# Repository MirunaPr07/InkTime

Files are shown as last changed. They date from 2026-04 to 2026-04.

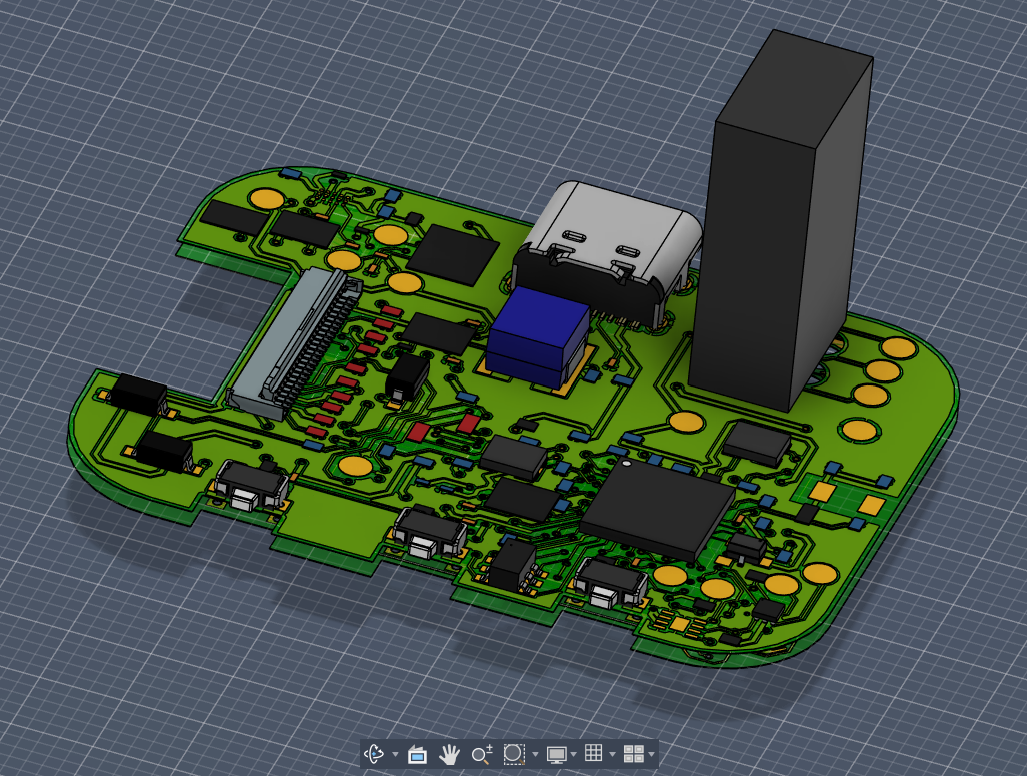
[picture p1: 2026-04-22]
Images/3d.png

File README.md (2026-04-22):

# InkWatch_TSC_Project

## Descriere

Proiectul meu este un smartwatch simplificat, cu focus pe consum redus și integrarea mai multor funcționalități pe un PCB mic. Am folosit un nRF52840 ca MCU principal și am conectat la el senzori, display e-paper și haptic.

Funcționalități:
- display e-paper
- BLE pentru comunicare
- accelerometru pentru mișcare
- feedback haptic
- încărcare USB-C

---

## Schema Bloc

```mermaid
graph TD

    USB["USB-C (J4)"] --> CHARGER["BQ25180 Charger"]
    CHARGER --> REG["RT6160 3.3V"]
    REG --> MCU["nRF52840 MCU + BLE"]

    BAT["LiPo Battery"] --> CHARGER
    BAT --> FUEL["MAX17048 Fuel Gauge"]
    FUEL --> MCU

    MCU -->|SPI| EPD["EPD Display (J1)"]
    MCU -->|I2C| IMU["BMA421 IMU"]
    MCU -->|I2C| HAPTIC["DRV2605 Haptic"]

    MCU --> BTN1["SW_UP"]
    MCU --> BTN2["SW_DN"]
    MCU --> BTN3["SW_ENT"]

    MCU --> ANT["2.4GHz Antenna"]

    MCU --> DEBUG["TC2030 SWD"]
```

## Bill of Materials

| Ref | Component | Package | Funcție | LCSC | Datasheet |
|-----|---|---|---|---|---|
| U1 | nRF52840-QIAA | QFN73 | MCU + BLE | [C190794](https://jlcpcb.com/partdetail/C190794) | https://infocenter.nordicsemi.com |
| IC1 | BQ25180YBGR | DSBGA-8 | Charger LiPo | [C3682423](https://jlcpcb.com/partdetail/C3682423) | https://www.ti.com |
| IC9 | RT6160AWSC | WLCSP-15 | Regulator 3.3V | [C7065276](https://jlcpcb.com/partdetail/C7065276) | https://www.richtek.com |
| U3 | MAX17048G+T10 | DFN | Fuel gauge | [C2682616](https://jlcpcb.com/partdetail/C2682616) | https://www.analog.com |
| IC3 | BMA421 | LGA | IMU | [C5242966](https://jlcpcb.com/partdetail/C5242966) | https://www.bosch-sensortec.com |
| IC2 | DRV2605L | VSSOP | Haptic driver | [C527464](https://jlcpcb.com/partdetail/C527464) | https://www.ti.com |
| D3 | USBLC6 | SOT-23-6 | ESD USB | [C2687116](https://jlcpcb.com/partdetail/C2687116) | https://www.st.com |
| J4 | USB-C | SMD | Conector alimentare | [C165948](https://jlcpcb.com/partdetail/C165948) | - |
| J1 | FPC 24 pini | SMD | Conector display | [C393234](https://jlcpcb.com/partdetail/C393234) | - |
| J2 | TC2030 | PTH | Debug SWD | - | - |
| ANT1 | 2450AT18B100E | SMD | Antenă BLE | - | https://www.johansontechnology.com |

---

## Funcționalitate Hardware

### Power

USB-C (5V) -> BQ25180 -> RT6160 -> 3.3V -> sistem

- BQ25180 face charging + power path
- RT6160 generează 3.3V stabil
- MAX17048 citește nivelul bateriei

---

### MCU - nRF52840

Este componenta principală:
- BLE integrat
- controlează toate perifericele

---

### Display E-Paper

Conectat prin SPI:
- SCK - P0.02
- MOSI - P0.03
- CS - P0.05
- DC - P0.15
- RST - P0.16
- BUSY - P0.17

---

### IMU - BMA421

- I2C (SDA P0.06 / SCL P0.07)
- interrupt pe P0.08 și P1.08

---

### Haptic – DRV2605

- I2C
- enable pe P0.12

---

### USB

- USB-C pentru alimentare
- protecție ESD (USBLC6)

---

## Pini nRF52840

| Pin | Semnal | Funcție |
|-----|---|---|
| P0.02 | SCK | SPI |
| P0.03 | MOSI | SPI |
| P0.05 | CS | Display |
| P0.06 | SDA | I2C |
| P0.07 | SCL | I2C |
| P0.08 | INT1 | IMU |
| P0.12 | HAPTIC_EN | Haptic |
| P0.13 | SW_UP | Buton |
| P0.14 | SW_DN | Buton |
| P0.15 | DC | Display |
| P0.16 | RST | Display |
| P0.17 | BUSY | Display |
| P1.00 | SW_ENT | Buton |
| P1.01 | EPD_PWR | Power gate |
| P1.08 | INT2 | IMU |
| P0.24 | SWDCLK | Debug |
| P0.25 | SWDIO | Debug |

---

## PCB Design

- 2 layere (Top + Bottom)
- GND polygon pour pe ambele
- trasee:
  - power: 0.3mm
  - semnal: 0.15mm

### Decizii:
- antena la margine cu keepout
- decuplare lângă IC-uri
- rutare manuală pentru trasee critice

---

## Observații

- rutare destul de densă în zona MCU
- unele trasee mai subțiri în zona BGA
- câteva GND trase manual

---

## Concluzie

Proiectul este complet funcțional din punct de vedere hardware și include toate modulele necesare pentru un smartwatch simplu.

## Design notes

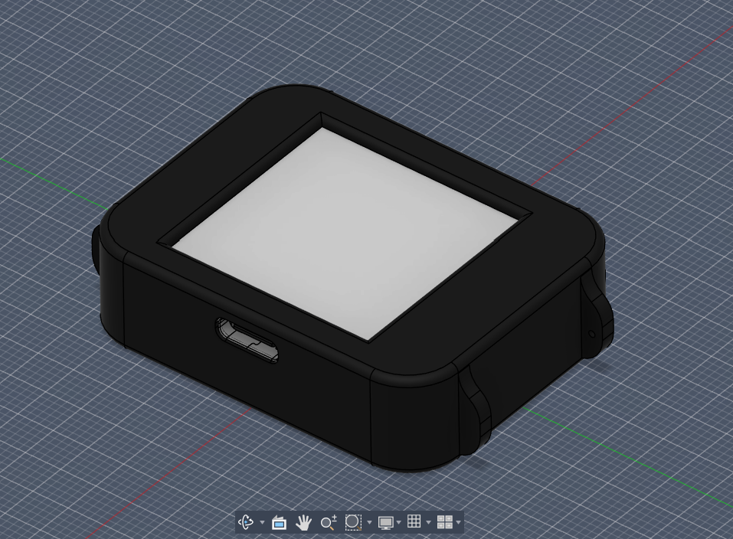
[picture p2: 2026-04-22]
Images/carcasa.png

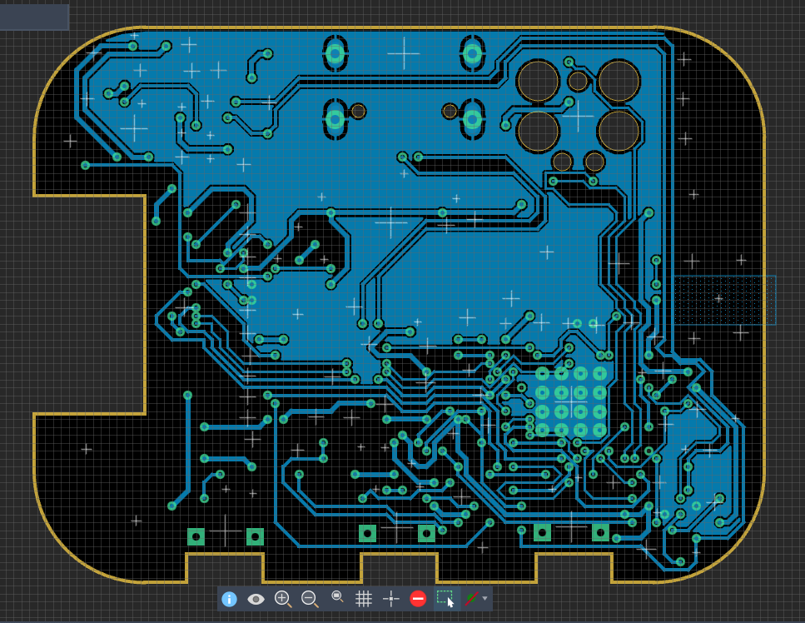
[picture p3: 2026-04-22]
Images/2d_bottom.png

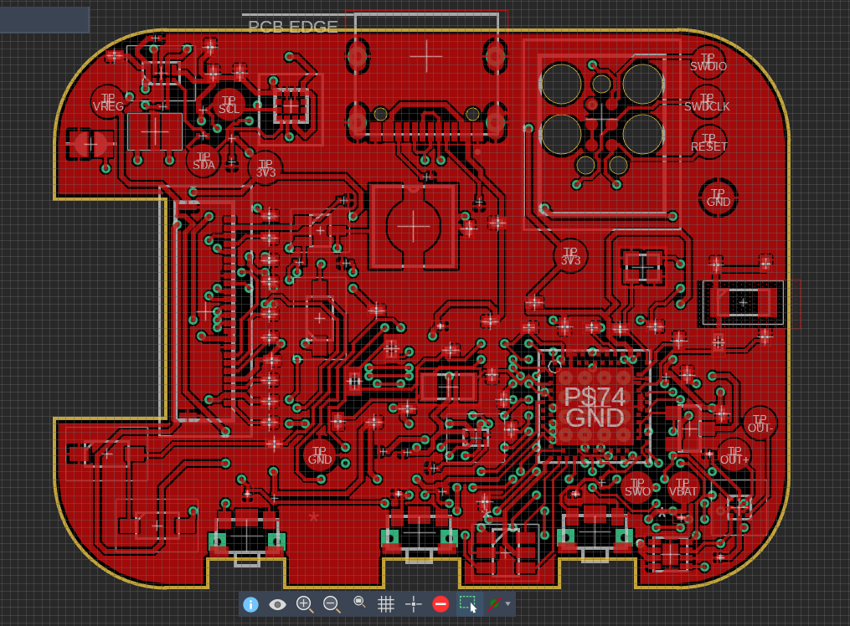
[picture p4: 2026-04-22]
Images/2d_top.png

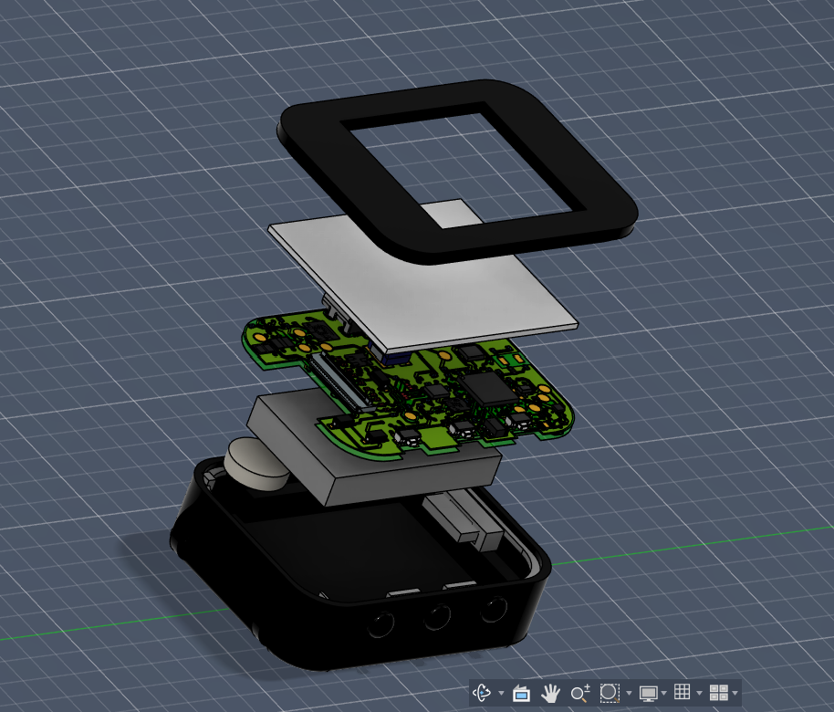
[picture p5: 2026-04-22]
Images/exploded_view.png

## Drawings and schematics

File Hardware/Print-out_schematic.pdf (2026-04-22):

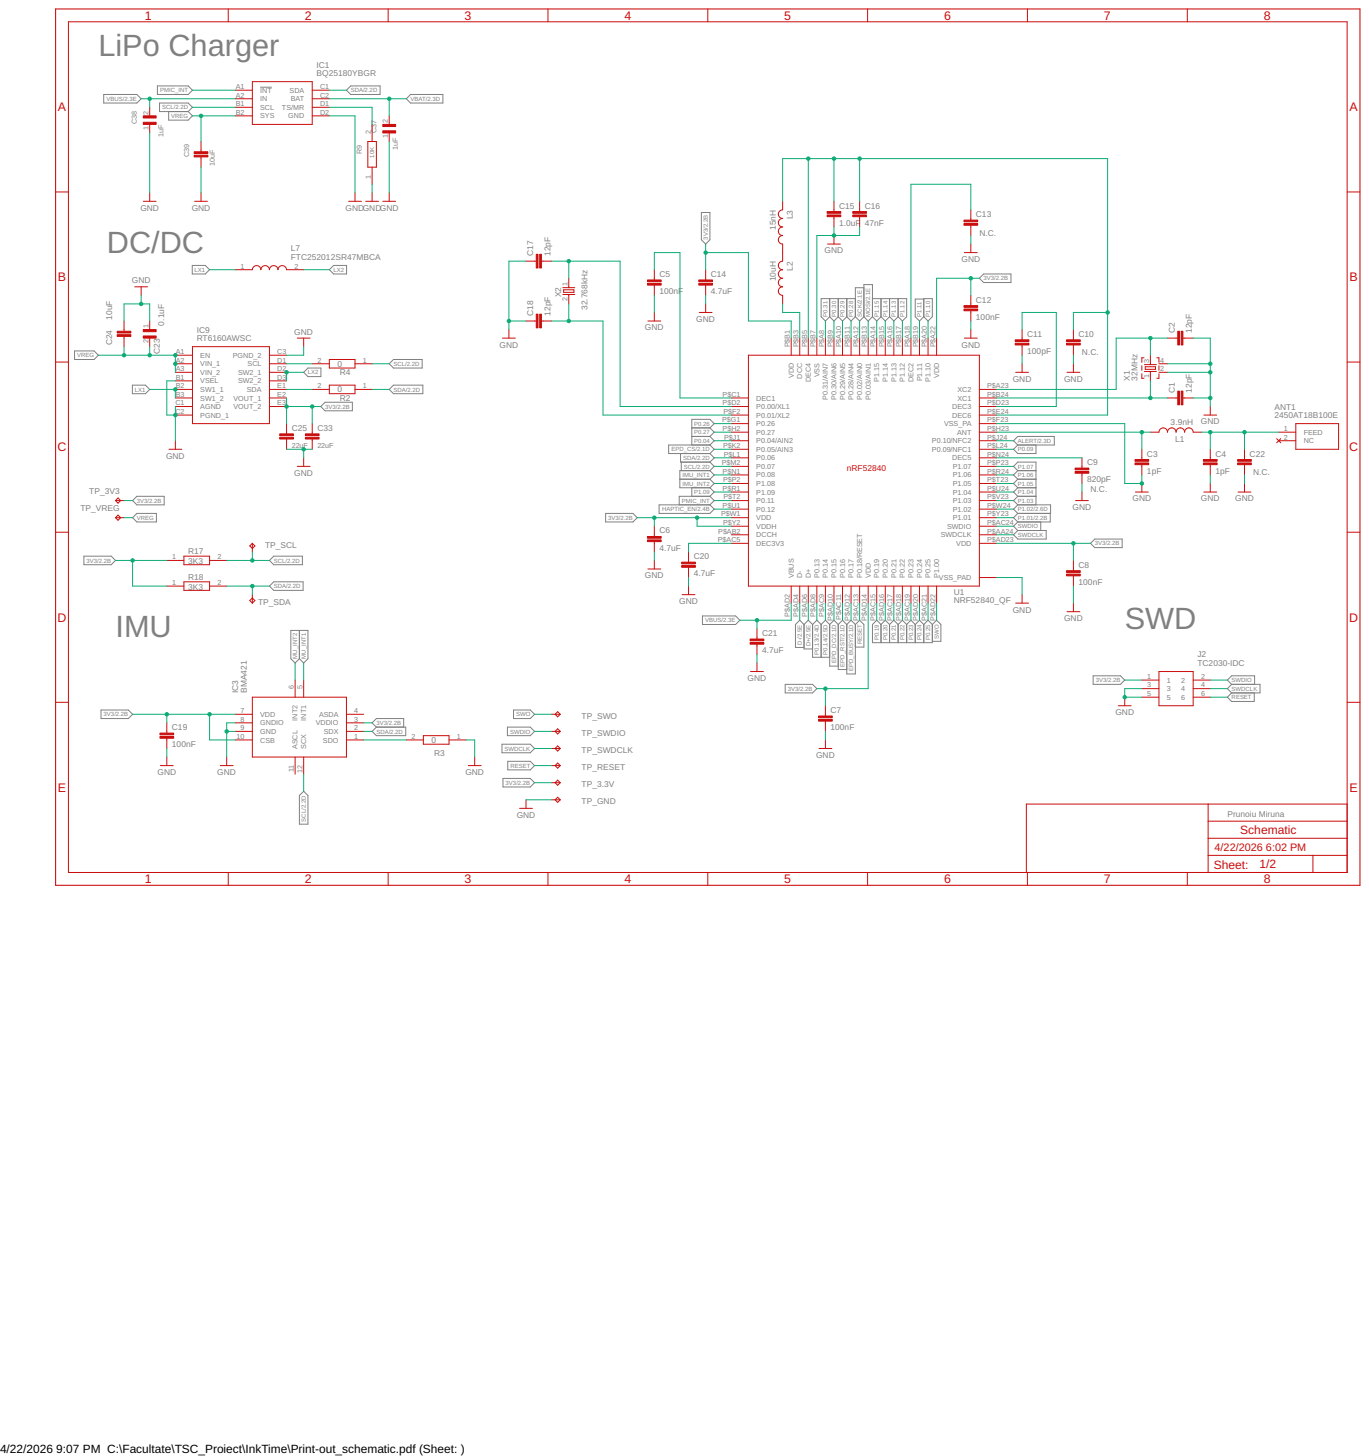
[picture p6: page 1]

4/22/2026 9:07 PM C:\Facultate\TSC_Proiect\InkTime\Print-out_schematic.pdf (Sheet: )

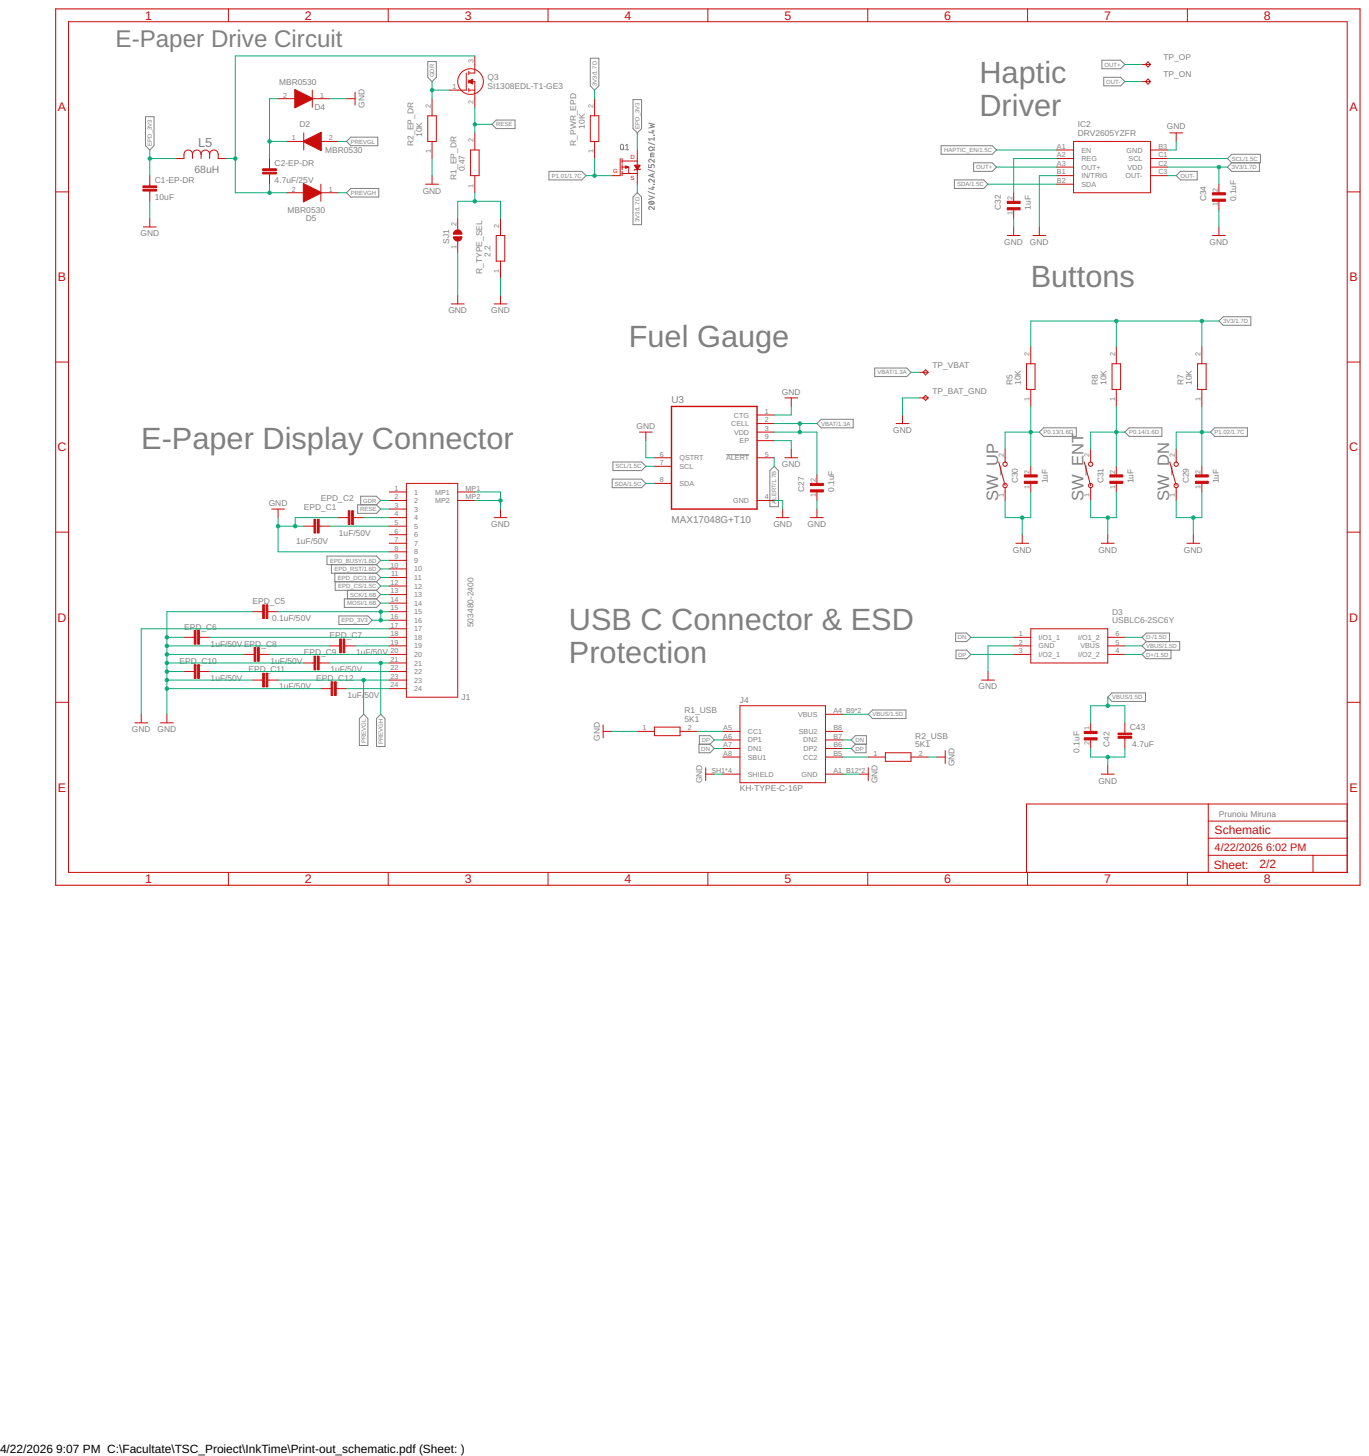
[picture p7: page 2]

EPD_C10 | 1uF/50V | 21

1uF/50V | EPD_C12 | 23

4/22/2026 9:07 PM C:\Facultate\TSC_Proiect\InkTime\Print-out_schematic.pdf (Sheet: )

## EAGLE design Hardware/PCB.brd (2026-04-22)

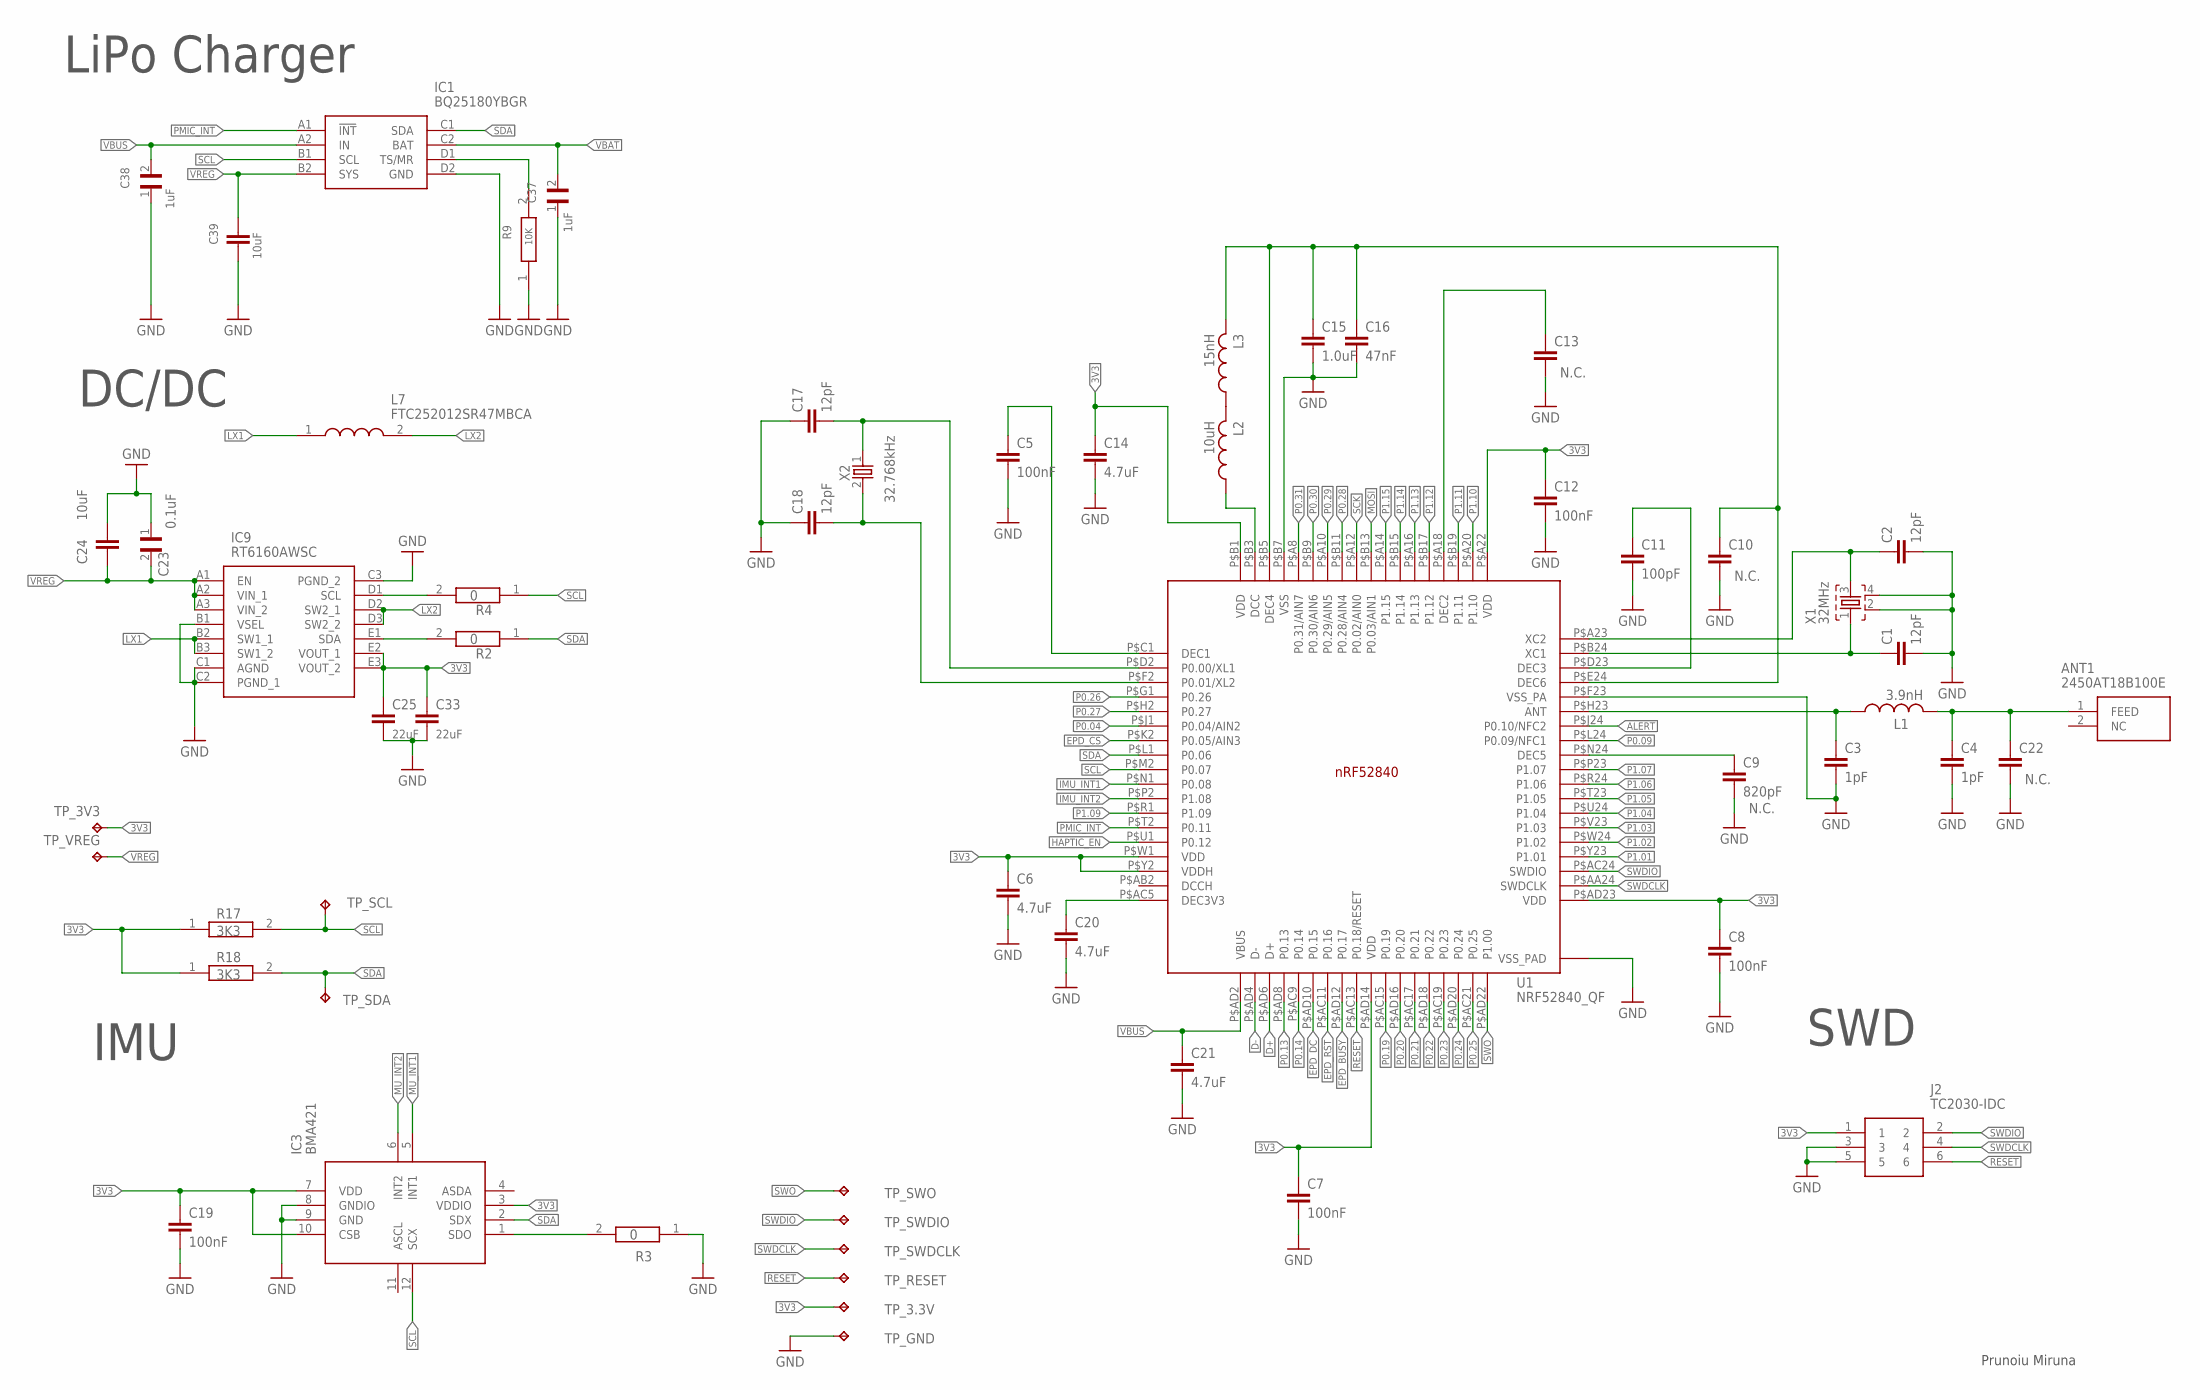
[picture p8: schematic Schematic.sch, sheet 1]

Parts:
ANT1: 2450AT18B100E; 2450AT18B100E_ANTC3216X140N
C1, C2, C17, C18: 12pF; NORDIC_NRF_3_RESC0201_L
C3, C4: 1pF; NORDIC_NRF_3_RESC0201_L
C5, C7, C8, C12, C19: 100nF; NORDIC_NRF_3_RESC0201_L
C6, C14, C20, C21: 4.7uF; NORDIC_NRF_3_RESC0201_L
C9: 820pF; NORDIC_NRF_3_RESC0201_L
C10, C13, C22: NORDIC_NRF_3_CAPACITOR_0201_L; NORDIC_NRF_3_RESC0201_L
C11: 100pF; NORDIC_NRF_3_RESC0201_L
C15: 1.0uF; NORDIC_NRF_3_RESC0201_L
C16: 47nF; NORDIC_NRF_3_RESC0201_L
C23: 0.1uF; GRM011R60J152KE01L_1_0201
C24, C39: 10uF; NORDIC_NRF_3_RESC0201_L
C25, C33: 22uF; NORDIC_NRF_3_RESC0201_L
C37, C38: 1uF; GRM011R60J152KE01L_1_0201
IC1: BQ25180YBGR; BQ25180YBGR_BGA8C40P2X4_100X155X50
IC3: BMA421; BMA423_BMA423
IC9: RT6160AWSC; RT6160AWSC_BGA15C40P3X5_140X230X60
J2: TC2030-IDC; TC2030-IDC_TC2030IDC
L1: 3.9nH; NORDIC_NRF_2_RESC0402_L
L2: 10uH; NORDIC_NRF_2_RESC0402_L
L3: 15nH; NORDIC_NRF_2_RESC0402_L
L7: FTC252012SR47MBCA; MLP2016SR47MT0S1_INDC2016X100N
R2, R3, R4: 0; CPF0201D7K68C1_0201
R9: 10K; CPF0201D7K68C1_0201
R17, R18: 3K3; CPF0201D7K68C1_0201
TP_3.3V, TP_3V3: HECTOR_WATCH_1_TPTP20R; HECTOR_WATCH_1_TP20R
TP_GND: HECTOR_WATCH_1_TPTP20R; HECTOR_WATCH_1_TP20R
TP_RESET: HECTOR_WATCH_1_TPTP20R; HECTOR_WATCH_1_TP20R
TP_SCL: HECTOR_WATCH_1_TPTP20R; HECTOR_WATCH_1_TP20R
TP_SDA: HECTOR_WATCH_1_TPTP20R; HECTOR_WATCH_1_TP20R
TP_SWDCLK: HECTOR_WATCH_1_TPTP20R; HECTOR_WATCH_1_TP20R
TP_SWDIO: HECTOR_WATCH_1_TPTP20R; HECTOR_WATCH_1_TP20R
TP_SWO: HECTOR_WATCH_1_TPTP20R; HECTOR_WATCH_1_TP20R
TP_VREG: HECTOR_WATCH_1_TPTP20R; HECTOR_WATCH_1_TP20R
U1: NRF52840_QF; NORDIC_NRF_4_AQFN50P700X700X85_HS-74N
X1: 32MHz; NORDIC_NRF_BT-XTAL_2016_N
X2: 32.768kHz; NORDIC_NRF_1_XTAL_3215_N

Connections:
3V3: C6.1, C7.1, C8.1, C12.1, C14.1, C19.1, C25.1, C33.1, IC3.3 (VDDIO), IC3.7 (VDD), IC3.10 (CSB), IC9.E2 (VOUT_1), IC9.E3 (VOUT_2), J2.1, R17.1, R18.1, TP_3.3V.TP, TP_3V3.TP, U1.P$A22 (VDD), U1.P$AD14 (VDD), U1.P$AD23 (VDD), U1.P$B1 (VDD), U1.P$W1 (VDD), U1.P$Y2 (VDDH); also elsewhere on the board
ALERT: U1.P$J24 (P0.10/NFC2); also elsewhere on the board
D+: U1.P$AD6 (D+); also elsewhere on the board
D-: U1.P$AD4 (D-); also elsewhere on the board
DEC1: C5.1, U1.P$C1 (DEC1)
DEC3: C11.1, U1.P$D23 (DEC3)
DEC4_6: C10.1, C15.1, C16.1, L3.2, U1.P$B5 (DEC4), U1.P$E24 (DEC6)
EPD_BUSY: U1.P$AD12 (P0.17); also elsewhere on the board
EPD_CS: U1.P$K2 (P0.05/AIN3); also elsewhere on the board
EPD_DC: U1.P$AD10 (P0.15); also elsewhere on the board
EPD_RST: U1.P$AC11 (P0.16); also elsewhere on the board
GND: C1.2, C2.2, C3.2, C4.2, C5.2, C6.2, C7.2, C8.2, C9.2, C10.2, C11.2, C12.2, C13.2, C14.2, C15.2, C16.2, C17.1, C18.1, C19.2, C20.2, C21.2, C22.2, C23.1, C24.1, C25.2, C33.2, C37.1, C38.1, C39.2, IC1.D2 (GND), IC3.8 (GNDIO), IC3.9 (GND), IC9.B1 (VSEL), IC9.C1 (AGND), IC9.C2 (PGND_1), IC9.C3 (PGND_2), J2.3, J2.5, R3.1, R9.1, TP_GND.TP, U1.P$74 (VSS_PAD), U1.P$75 (VSS_PAD), U1.P$76 (VSS_PAD), U1.P$77 (VSS_PAD), U1.P$78 (VSS_PAD), U1.P$79 (VSS_PAD), U1.P$80 (VSS_PAD), U1.P$81 (VSS_PAD), U1.P$82 (VSS_PAD), U1.P$83 (VSS_PAD), U1.P$84 (VSS_PAD), U1.P$85 (VSS_PAD), U1.P$86 (VSS_PAD), U1.P$87 (VSS_PAD), U1.P$88 (VSS_PAD), U1.P$89 (VSS_PAD), U1.P$90 (VSS_PAD), U1.P$B7 (VSS), U1.P$F23 (VSS_PA), X1.2, X1.4; also elsewhere on the board
HAPTIC_EN: U1.P$U1 (P0.12); also elsewhere on the board
IMU_INT1: U1.P$N1 (P0.08)
IMU_INT2: U1.P$P2 (P1.08)
LX1: IC9.B2 (SW1_1), IC9.B3 (SW1_2), L7.1
LX2: IC9.D2 (SW2_1), IC9.D3 (SW2_2), L7.2
MOSI: U1.P$B13 (P0.03/AIN1); also elsewhere on the board
MU_INT1: IC3.5 (INT1)
MU_INT2: IC3.6 (INT2)
unnamed: IC3.1 (SDO), R3.2
unnamed: IC9.E1 (SDA), R2.2
unnamed: IC9.D1 (SCL), R4.2
unnamed: C9.1, U1.P$N24 (DEC5)
unnamed: IC1.D1 (TS/MR), R9.2
unnamed: C13.1, U1.P$A18 (DEC2)
unnamed: C3.1, L1.1, U1.P$H23 (ANT)
unnamed: C1.1, U1.P$B24 (XC1), X1.1
unnamed: C2.1, U1.P$A23 (XC2), X1.3
unnamed: L2.2, L3.1
unnamed: L2.1, U1.P$B3 (DCC)
unnamed: C20.1, U1.P$AC5 (DEC3V3)
P0.00/XL1: C17.2, U1.P$D2 (P0.00/XL1), X2.1
P0.01/XL2: C18.2, U1.P$F2 (P0.01/XL2), X2.2
P0.04: U1.P$J1 (P0.04/AIN2)
P0.09: U1.P$L24 (P0.09/NFC1)
P0.13: U1.P$AD8 (P0.13); also elsewhere on the board
P0.14: U1.P$AC9 (P0.14); also elsewhere on the board
P0.19: U1.P$AC15 (P0.19)
P0.20: U1.P$AD16 (P0.20)
P0.21: U1.P$AC17 (P0.21)
P0.22: U1.P$AD18 (P0.22)
P0.23: U1.P$AC19 (P0.23)
P0.24: U1.P$AD20 (P0.24)
P0.25: U1.P$AC21 (P0.25)
P0.26: U1.P$G1 (P0.26)
P0.27: U1.P$H2 (P0.27)
P0.28: U1.P$B11 (P0.28/AIN4)
P0.29: U1.P$A10 (P0.29/AIN5)
P0.30: U1.P$B9 (P0.30/AIN6)
P0.31: U1.P$A8 (P0.31/AIN7)
P1.01: U1.P$Y23 (P1.01); also elsewhere on the board
P1.02: U1.P$W24 (P1.02); also elsewhere on the board
P1.03: U1.P$V23 (P1.03)
P1.04: U1.P$U24 (P1.04)
P1.05: U1.P$T23 (P1.05)
P1.06: U1.P$R24 (P1.06)
P1.07: U1.P$P23 (P1.07)
P1.09: U1.P$R1 (P1.09)
P1.10: U1.P$A20 (P1.10)
P1.11: U1.P$B19 (P1.11)
P1.12: U1.P$B17 (P1.12)
P1.13: U1.P$A16 (P1.13)
P1.14: U1.P$B15 (P1.14)
P1.15: U1.P$A14 (P1.15)
PMIC_INT: IC1.A1 (!INT), U1.P$T2 (P0.11)
RESET: J2.6, TP_RESET.TP, U1.P$AC13 (P0.18/RESET)
RF: ANT1.1 (FEED), C4.1, C22.1, L1.2
SCK: U1.P$A12 (P0.02/AIN0); also elsewhere on the board
SCL: IC1.B1 (SCL), IC3.12 (SCX), R4.1, R17.2, TP_SCL.TP, U1.P$M2 (P0.07); also elsewhere on the board
SDA: IC1.C1 (SDA), IC3.2 (SDX), R2.1, R18.2, TP_SDA.TP, U1.P$L1 (P0.06); also elsewhere on the board
SWDCLK: J2.4, TP_SWDCLK.TP, U1.P$AA24 (SWDCLK)
SWDIO: J2.2, TP_SWDIO.TP, U1.P$AC24 (SWDIO)
SWO: TP_SWO.TP, U1.P$AD22 (P1.00)
VBAT: C37.2, IC1.C2 (BAT); also elsewhere on the board
VBUS: C21.1, C38.2, IC1.A2 (IN), U1.P$AD2 (VBUS); also elsewhere on the board
VREG: C23.2, C24.2, C39.1, IC1.B2 (SYS), IC9.A1 (EN), IC9.A2 (VIN_1), IC9.A3 (VIN_2), TP_VREG.TP

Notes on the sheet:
IMU
LiPo Charger
DC/DC
SWD
Prunoiu Miruna

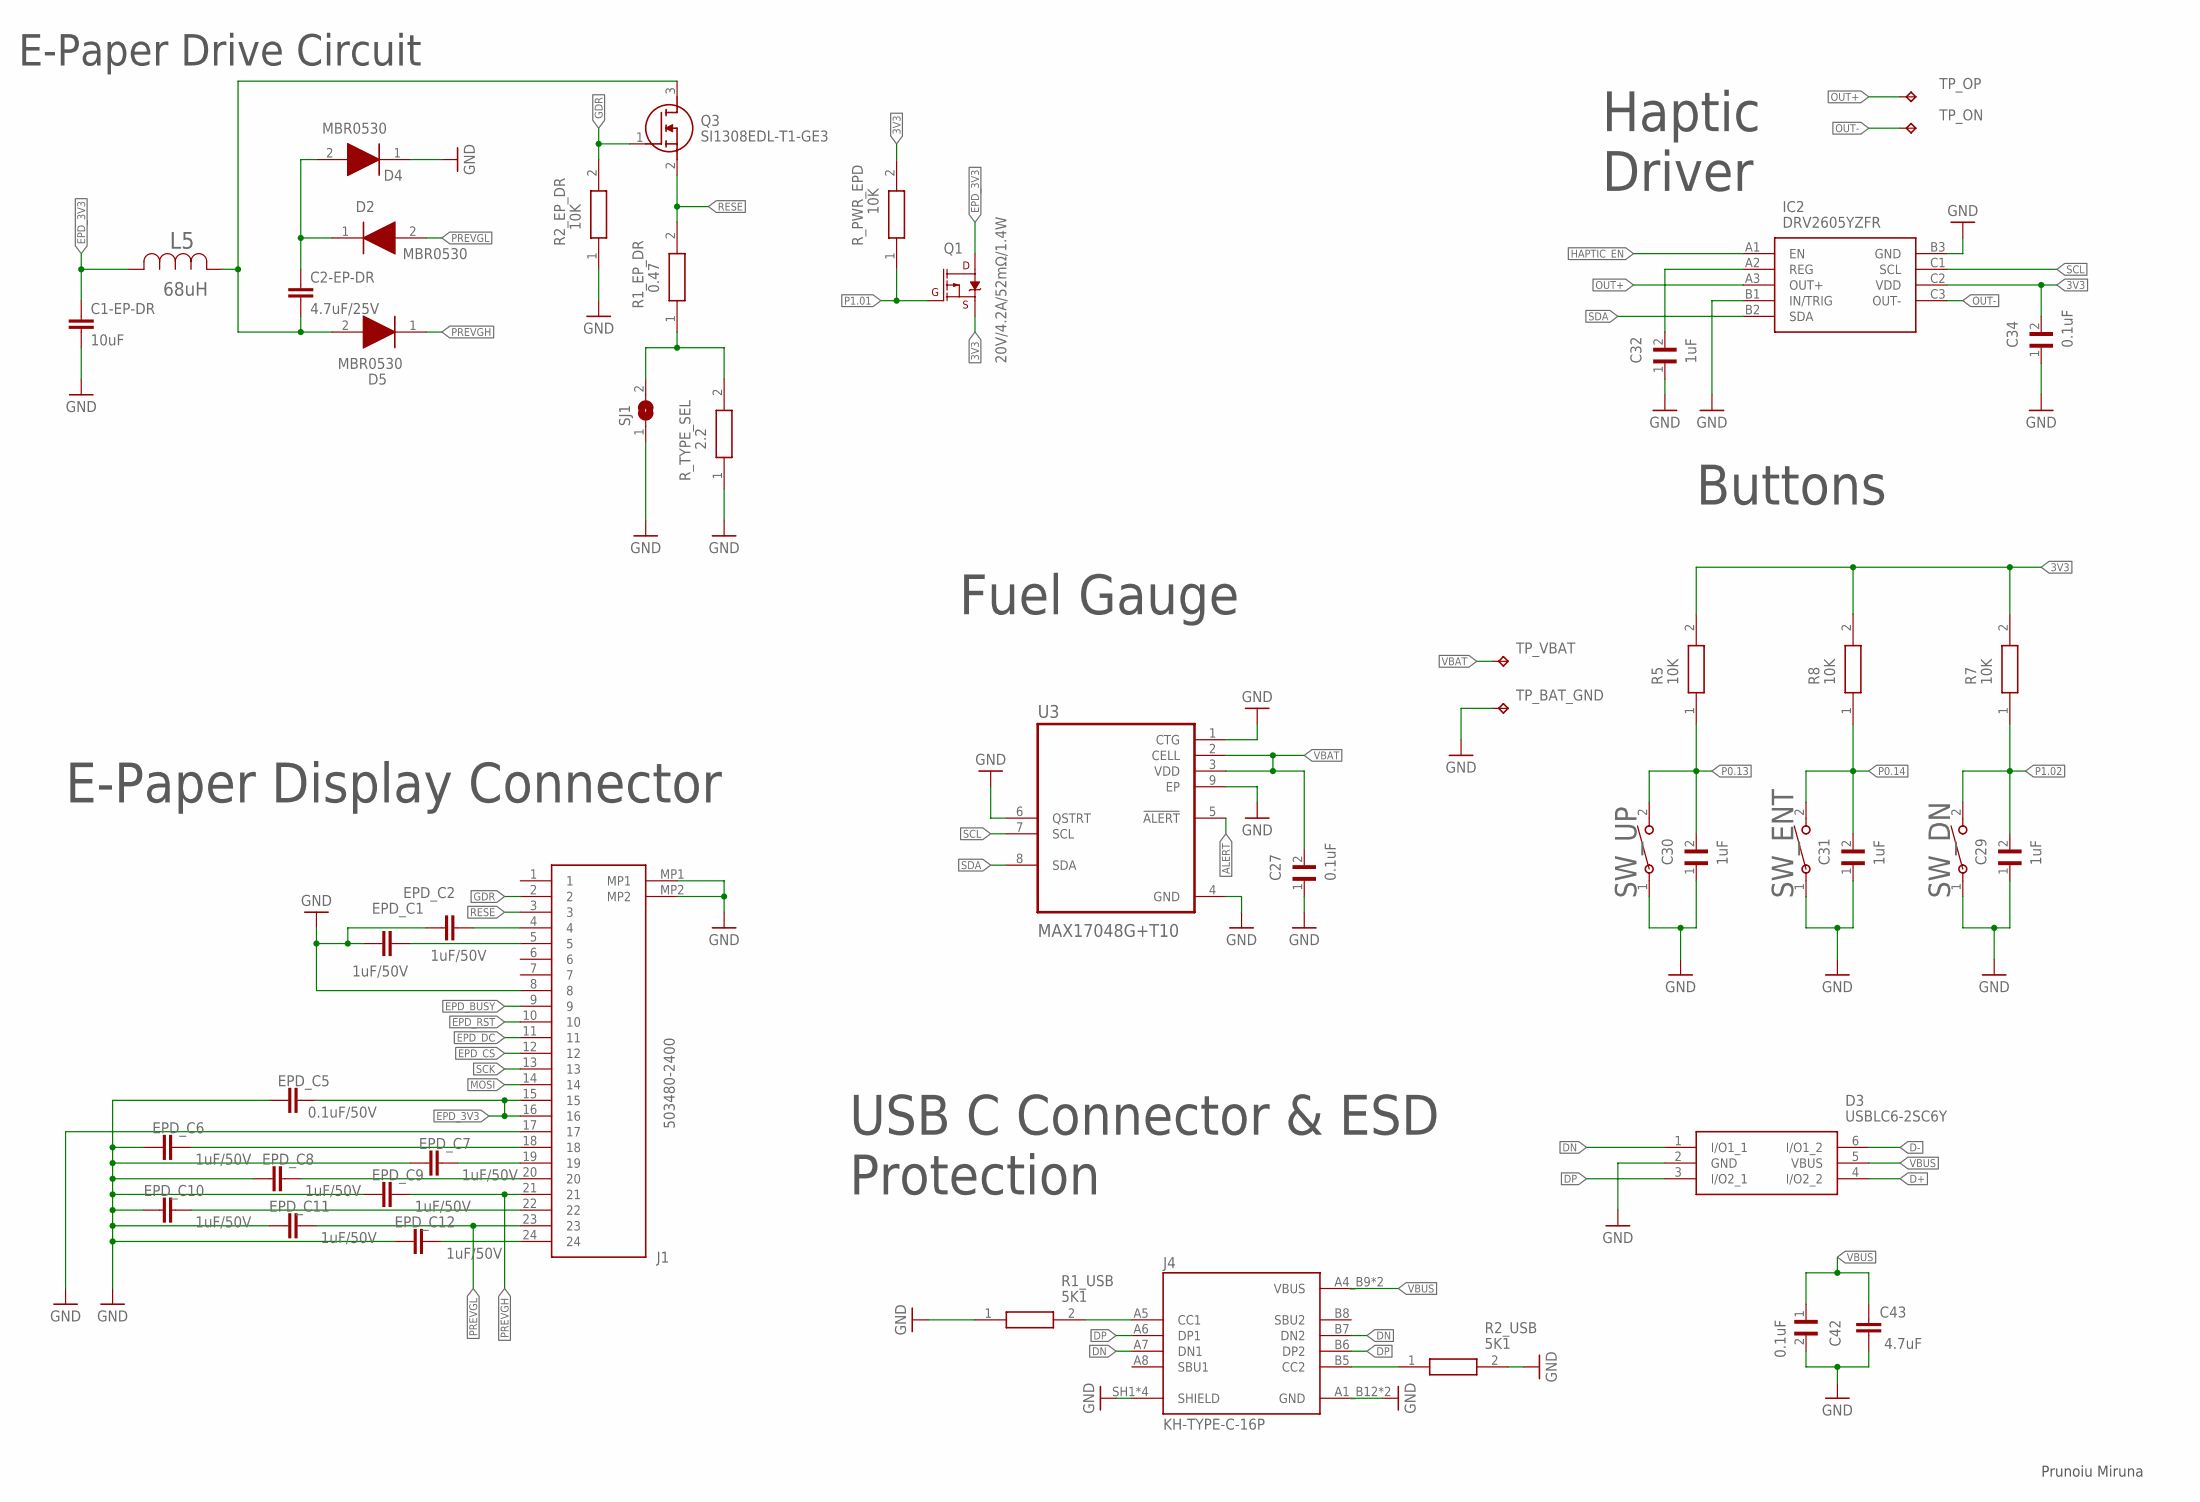
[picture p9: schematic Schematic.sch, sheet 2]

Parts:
C1-EP-DR: 10uF; NORDIC_NRF_3_RESC0201_L
C2-EP-DR: 4.7uF/25V; NORDIC_NRF_3_RESC0201_L
C27, C34, C42: 0.1uF; GRM011R60J152KE01L_2_CAPC0201X13N
C29, C30, C31, C32: 1uF; GRM011R60J152KE01L_2_CAPC0201X13N
C43: 4.7uF; NORDIC_NRF_3_RESC0201_L
D2, D4, D5: MBR0530; ESP32_C6_LIBRARY_5_SOD3716X135N
D3: USBLC6-2SC6Y; ESP32_C6_LIBRARY_3_SOT95P280X145-6N
EPD_C1, EPD_C2, EPD_C6, EPD_C7, EPD_C8, EPD_C9, EPD_C10, EPD_C11, EPD_C12: 1uF/50V; NORDIC_NRF_3_RESC0201_L
EPD_C5: 0.1uF/50V; NORDIC_NRF_3_RESC0201_L
IC2: DRV2605YZFR; DRV2605YZFR_BGA9C50P3X3_144X144X62
J1: 503480-2400; 503480-2400_5034802400
J4: KH-TYPE-C-16P; KH-TYPE-C-16P_KINGHELM_KH-TYPE-C-16P
L5: 68uH; ESP32_C6_LIBRARY_2_IND_4828-WE-TPC_WRE
Q1: 20V/4.2A/52mΩ/1.4W; ESP32_C6_LIBRARY_4_ESP32_C6_LIBRARY_4_ESP32_C6_LIBRARY_4_ES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
Q3: SI1308EDL-T1-GE3; ESP32_C6_LIBRARY_6_SOT65P210X110-3N
R1_EP_DR: 0.47; CPF0201D7K68C1_0201
R1_USB, R2_USB: 5K1; CPF0201D7K68C1_0201
R2_EP_DR, R5, R7, R8: 10K; CPF0201D7K68C1_0201
R_PWR_EPD: 10K; CPF0201D7K68C1_0201
R_TYPE_SEL: 2.2; CPF0201D7K68C1_0201
SJ1: ESP32_C6_LIBRARY_7_JUMPER_SJ
SW_DN: 2025-10-22_07-23-44_LIBRARY_EVP-AKE31ASW_EVP-AKE3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; 2025-10-22_07-23-44_LIBRARY_SW_EVP-AKE31A_PAN
SW_ENT: 2025-10-22_07-23-44_LIBRARY_EVP-AKE31ASW_EVP-AKE3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; 2025-10-22_07-23-44_LIBRARY_SW_EVP-AKE31A_PAN
SW_UP: 2025-10-22_07-23-44_LIBRARY_EVP-AKE31ASW_EVP-AKE3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; 2025-10-22_07-23-44_LIBRARY_SW_EVP-AKE31A_PAN
TP_BAT_GND: HECTOR_WATCH_1_TPTP20R; HECTOR_WATCH_1_TP20R
TP_ON: HECTOR_WATCH_1_TPTP20R; HECTOR_WATCH_1_TP20R
TP_OP: HECTOR_WATCH_1_TPTP20R; HECTOR_WATCH_1_TP20R
TP_VBAT: HECTOR_WATCH_1_TPTP20R; HECTOR_WATCH_1_TP20R
U3: MAX17048G+T10; ESP32_C6_LIBRARY_SON50P200X200X80-9N

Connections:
3V3: C34.2, IC2.C2 (VDD), Q1.2 (S), R5.2, R7.2, R8.2, R_PWR_EPD.2; also elsewhere on the board
ALERT: U3.5 (!ALERT); also elsewhere on the board
D+: D3.4 (I/O2_2); also elsewhere on the board
D-: D3.6 (I/O1_2); also elsewhere on the board
DN: D3.1 (I/O1_1), J4.A7 (DN1), J4.B7 (DN2)
DP: D3.3 (I/O2_1), J4.A6 (DP1), J4.B6 (DP2)
EPD_3V3: C1-EP-DR.1, EPD_C5.2, J1.15, J1.16, L5.2, Q1.3 (D)
EPD_BUSY: J1.9; also elsewhere on the board
EPD_CS: J1.12; also elsewhere on the board
EPD_DC: J1.11; also elsewhere on the board
EPD_RST: J1.10; also elsewhere on the board
GDR: J1.2, Q3.1 (G), R2_EP_DR.2
GND: C1-EP-DR.2, C27.1, C29.1, C30.1, C31.1, C32.1, C34.1, C42.2, C43.1, D3.2 (GND), D4.1 (K), EPD_C1.1, EPD_C2.1, EPD_C5.1, EPD_C6.1, EPD_C7.1, EPD_C8.1, EPD_C9.1, EPD_C10.1, EPD_C11.1, EPD_C12.1, IC2.B1 (IN/TRIG), IC2.B3 (GND), J1.8, J1.17, J1.MP1, J1.MP2, J4.A1_B12 (GND), J4.A12_B1 (GND), J4.SH1 (SHIELD), J4.SH2 (SHIELD), J4.SH3 (SHIELD), J4.SH4 (SHIELD), R1_USB.1, R2_EP_DR.1, R2_USB.2, R_TYPE_SEL.1, SJ1.1, SW_DN.1, SW_ENT.1, SW_UP.1, TP_BAT_GND.TP, U3.1 (CTG), U3.4 (GND), U3.6 (QSTRT), U3.9 (EP); also elsewhere on the board
HAPTIC_EN: IC2.A1 (EN); also elsewhere on the board
MOSI: J1.14; also elsewhere on the board
unnamed: C32.2, IC2.A2 (REG)
unnamed: C2-EP-DR.2, D5.2 (A), L5.1, Q3.3 (D)
unnamed: C2-EP-DR.1, D2.1 (K), D4.2 (A)
unnamed: J4.A5 (CC1), R1_USB.2
unnamed: J4.B5 (CC2), R2_USB.1
unnamed: EPD_C2.2, J1.4
unnamed: EPD_C1.2, J1.5
unnamed: R1_EP_DR.1, R_TYPE_SEL.2, SJ1.2
unnamed: EPD_C6.2, J1.18
unnamed: EPD_C7.2, J1.19
unnamed: EPD_C8.2, J1.20
unnamed: EPD_C10.2, J1.22
unnamed: EPD_C12.2, J1.24
OUT+: IC2.A3 (OUT+), TP_OP.TP
OUT-: IC2.C3 (OUT-), TP_ON.TP
P0.13: C30.2, R5.1, SW_UP.2; also elsewhere on the board
P0.14: C31.2, R8.1, SW_ENT.2; also elsewhere on the board
P1.01: Q1.1 (G), R_PWR_EPD.1; also elsewhere on the board
P1.02: C29.2, R7.1, SW_DN.2; also elsewhere on the board
PREVGH: D5.1 (K), EPD_C9.2, J1.21
PREVGL: D2.2 (A), EPD_C11.2, J1.23
RESE: J1.3, Q3.2 (S), R1_EP_DR.2
SCK: J1.13; also elsewhere on the board
SCL: IC2.C1 (SCL), U3.7 (SCL); also elsewhere on the board
SDA: IC2.B2 (SDA), U3.8 (SDA); also elsewhere on the board
VBAT: C27.2, TP_VBAT.TP, U3.2 (CELL), U3.3 (VDD); also elsewhere on the board
VBUS: C42.1, C43.2, D3.5 (VBUS), J4.A4_B9 (VBUS), J4.A9_B4 (VBUS); also elsewhere on the board

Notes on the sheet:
E-Paper Drive Circuit
Haptic Driver
USB C Connector & ESD Protection
Buttons
Fuel Gauge
E-Paper Display Connector
Prunoiu Miruna

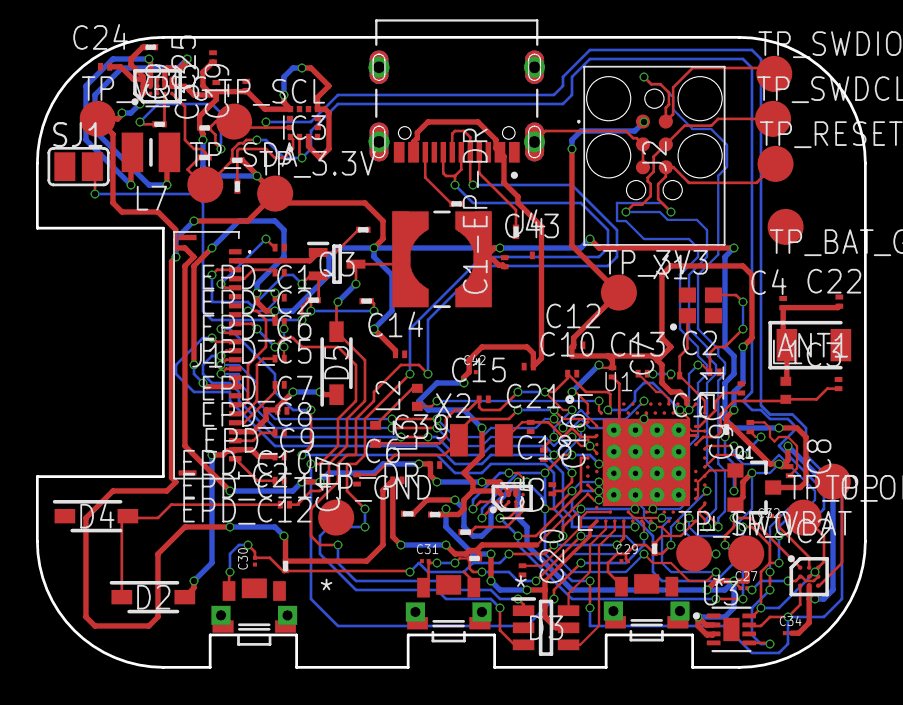
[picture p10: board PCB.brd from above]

Board: 2 copper layers, 46.0 x 35.0 mm, 105 parts (0 on the bottom side), 68 nets.

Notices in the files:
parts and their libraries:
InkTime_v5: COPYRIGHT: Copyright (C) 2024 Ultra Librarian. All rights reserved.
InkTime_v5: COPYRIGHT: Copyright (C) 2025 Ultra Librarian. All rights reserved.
